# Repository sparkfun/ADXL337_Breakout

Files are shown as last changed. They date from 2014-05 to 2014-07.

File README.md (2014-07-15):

ADXL337 Breakout
================

[ADXL337 Breakout   
*Triple Axis Accelerometer Breakout-ADXL337 (SEN-12786)*](https://www.sparkfun.com/products/12786)

A Breakout Board for the ADXL337 Low Power 3-Axis ±3 g Accelerometer with Analog Output.

Repository Contents
-------------------
* **/Hardware** - All Eagle design files (.brd, .sch)
* **/Production** - Test bed files and production panel files
* **/Firmware** - All Arduino sketches for this product

License Information
-------------------
The hardware is released under [Creative Commons ShareAlike 4.0 International](https://creativecommons.org/licenses/by-sa/4.0/).

Distributed as-is; no warranty is given.

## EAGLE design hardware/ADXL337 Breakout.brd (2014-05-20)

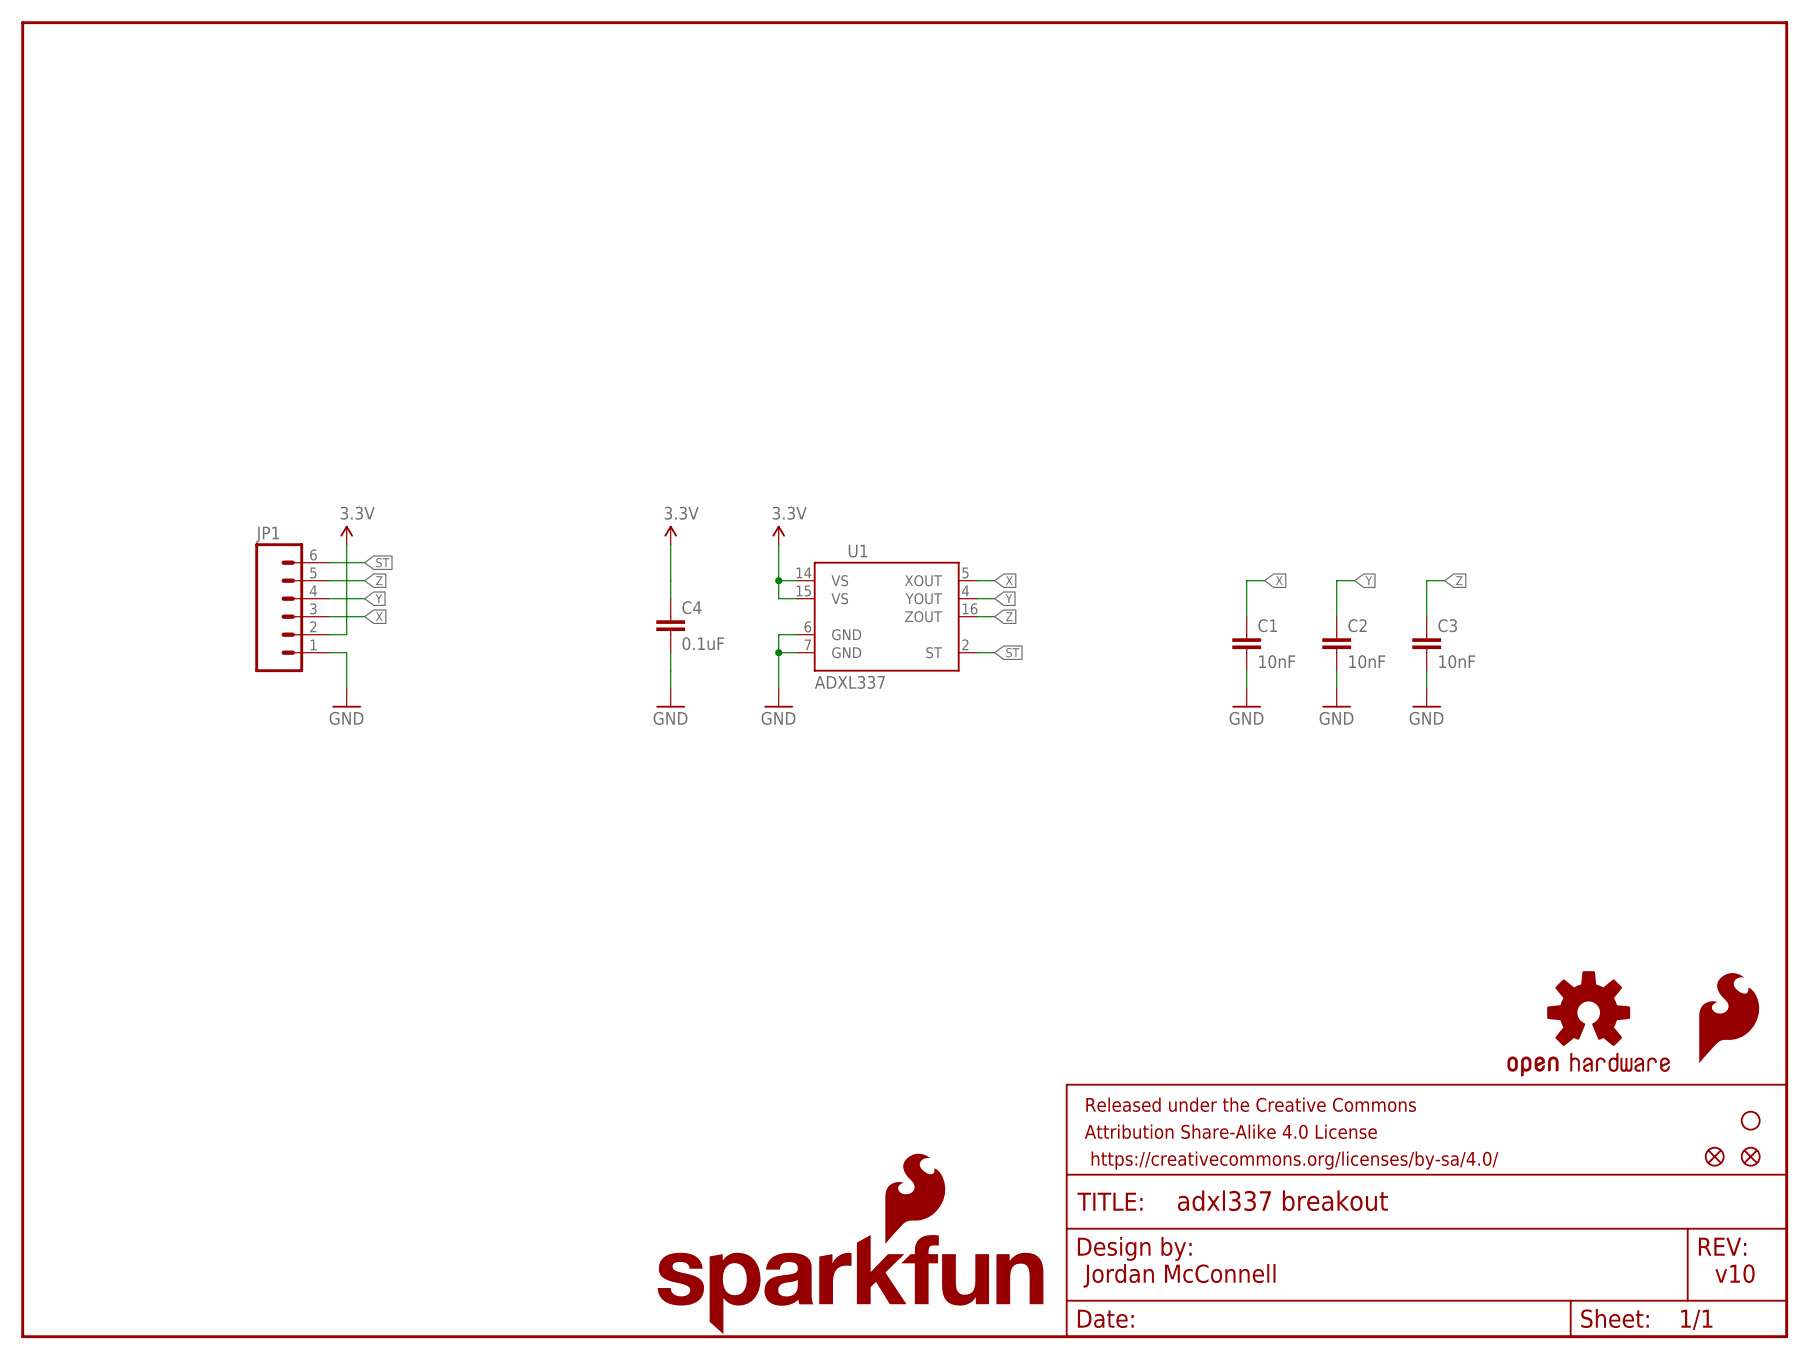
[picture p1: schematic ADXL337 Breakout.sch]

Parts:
C1, C2, C3: 10nF; 0603-CAP
C4: 0.1uF; 0603-CAP
FID1, FID2: FIDUCIAL1X2; FIDUCIAL-1X2
FRAME1: FRAME-LETTER; CREATIVE_COMMONS
JP1: M06SIP; 1X06
LOGO1: SFE_LOGO_FLAME.1_INCH; SFE_LOGO_FLAME_.1
LOGO2: OSHW-LOGOS; OSHW-LOGO-S
LOGO3: SFE_LOGO_NAME_FLAME.1_INCH; SFE_LOGO_NAME_FLAME_.1
STANDOFF1: STAND-OFF
U1: ADXL337; LFCSP_LQ-16

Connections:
3.3V: C4.1, JP1.2, U1.14 (VS), U1.15 (VS)
GND: C1.2, C2.2, C3.2, C4.2, JP1.1, U1.6 (GND), U1.7 (GND)
ST: JP1.6, U1.2 (ST)
X: C1.1, JP1.3, U1.5 (XOUT)
Y: C2.1, JP1.4, U1.4 (YOUT)
Z: C3.1, JP1.5, U1.16 (ZOUT)

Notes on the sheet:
Jordan McConnell
v10

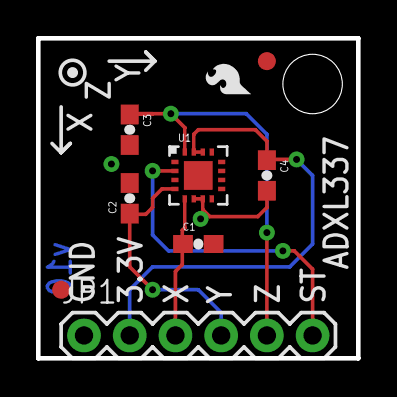
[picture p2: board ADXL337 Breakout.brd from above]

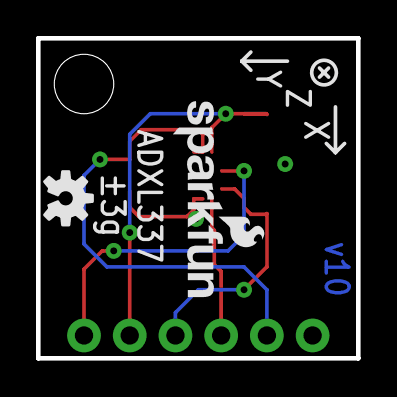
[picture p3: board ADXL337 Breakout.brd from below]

Board: 2 copper layers, 17.8 x 17.8 mm, 13 parts (2 on the bottom side), 6 nets.

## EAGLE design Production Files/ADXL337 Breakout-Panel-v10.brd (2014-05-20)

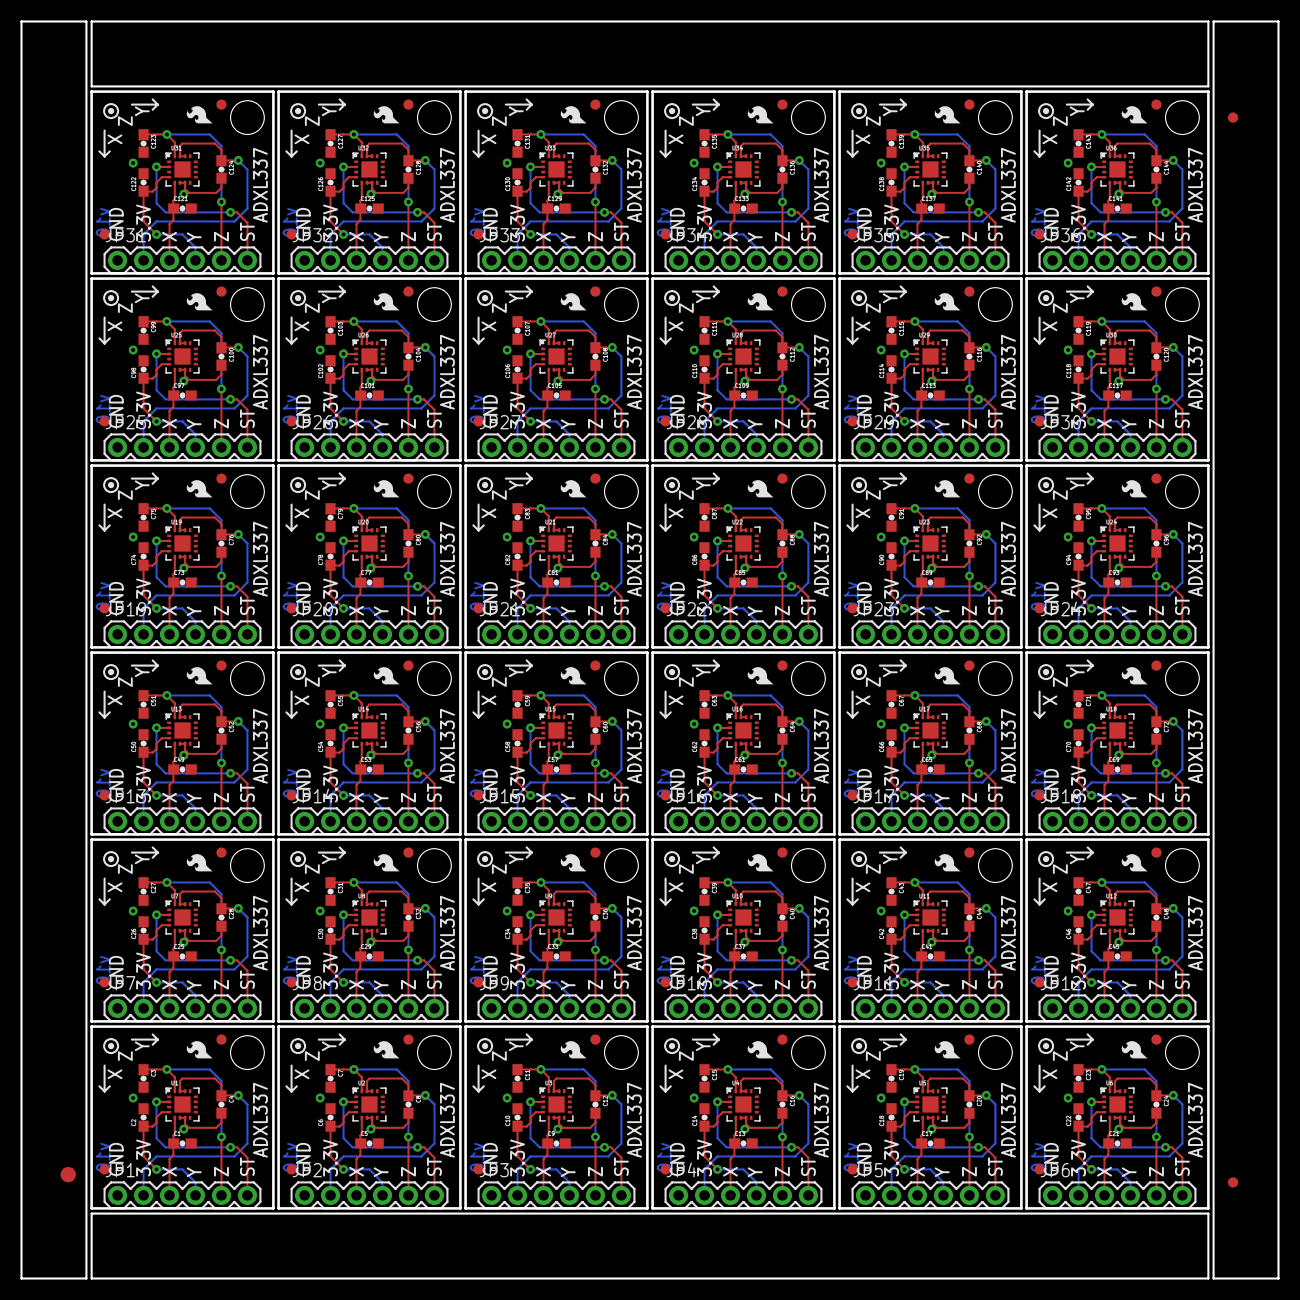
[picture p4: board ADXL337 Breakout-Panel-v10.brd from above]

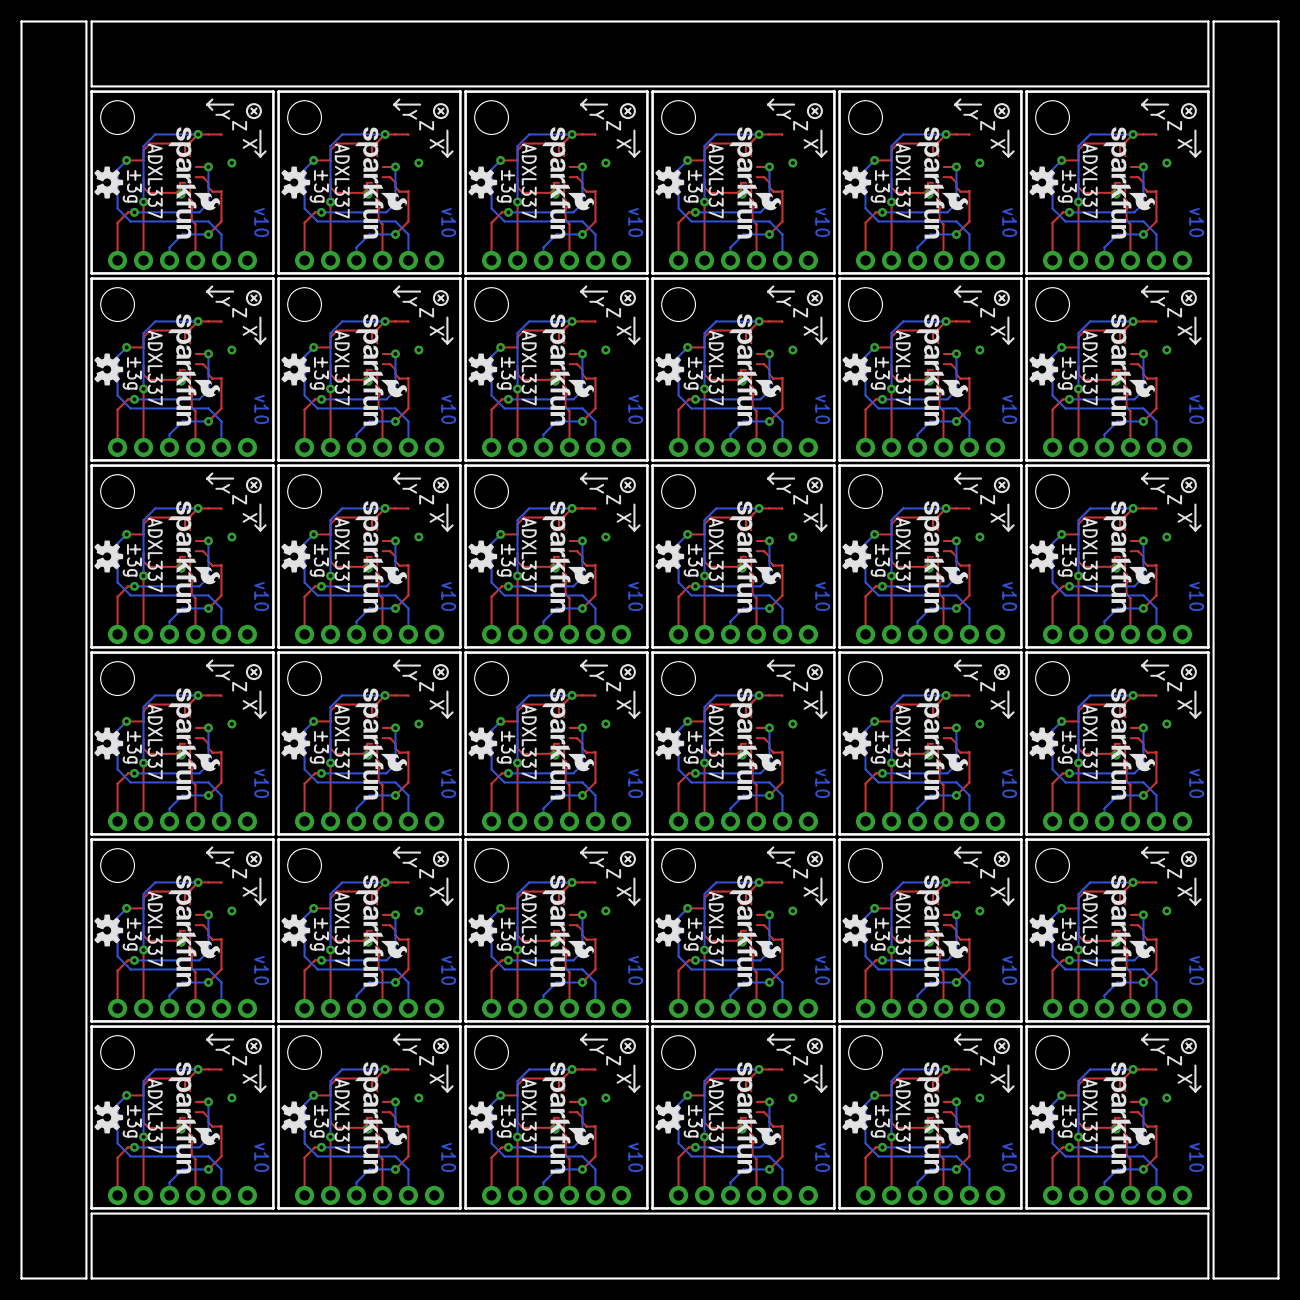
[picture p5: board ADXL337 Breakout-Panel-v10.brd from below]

Board: 2 copper layers, 122.9 x 122.9 mm, 435 parts (72 on the bottom side), 216 nets.

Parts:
C1, C2, C3, C5, C6, C7, C9, C10, C11, C13, C14, C15, C17, C18, C19, C21, C22, C23, C25, C26, C27, C29, C30, C31, C33, C34, C35, C37, C38, C39, C41, C42, C43, C45, C46, C47, C49, C50, C51, C53, C54, C55, C57, C58, C59, C61, C62, C63, C65, C66, C67, C69, C70, C71, C73, C74, C75, C77, C78, C79, C81, C82, C83, C85, C86, C87, C89, C90, C91, C93, C94, C95, C97, C98, C99, C101, C102, C103, C105, C106, C107, C109, C110, C111, C113, C114, C115, C117, C118, C119, C121, C122, C123, C125, C126, C127, C129, C130, C131, C133, C134, C135, C137, C138, C139, C141, C142, C143: 10nF; 0603-CAP
C4, C8, C12, C16, C20, C24, C28, C32, C36, C40, C44, C48, C52, C56, C60, C64, C68, C72, C76, C80, C84, C88, C92, C96, C100, C104, C108, C112, C116, C120, C124, C128, C132, C136, C140, C144: 0.1uF; 0603-CAP
E$1: FIDUCIAL-1.5X3
E$4, E$6: FIDUCIAL-1X2
FID1, FID2, FID3, FID4, FID5, FID6, FID7, FID8, FID9, FID10, FID11, FID12, FID13, FID14, FID15, FID16, FID17, FID18, FID19, FID20, FID21, FID22, FID23, FID24, FID25, FID26, FID27, FID28, FID29, FID30, FID31, FID32, FID33, FID34, FID35, FID36, FID37, FID38, FID39, FID40, FID41, FID42, FID43, FID44, FID45, FID46, FID47, FID48, FID49, FID50, FID51, FID52, FID53, FID54, FID55, FID56, FID57, FID58, FID59, FID60, FID61, FID62, FID63, FID64, FID65, FID66, FID67, FID68, FID69, FID70, FID71, FID72: FIDUCIAL1X2; FIDUCIAL-1X2
JP1, JP2, JP3, JP4, JP5, JP6, JP7, JP8, JP9, JP10, JP11, JP12, JP13, JP14, JP15, JP16, JP17, JP18, JP19, JP20, JP21, JP22, JP23, JP24, JP25, JP26, JP27, JP28, JP29, JP30, JP31, JP32, JP33, JP34, JP35, JP36: 1X06
LOGO1, LOGO4, LOGO7, LOGO10, LOGO13, LOGO16, LOGO19, LOGO22, LOGO25, LOGO28, LOGO31, LOGO34, LOGO37, LOGO40, LOGO43, LOGO46, LOGO49, LOGO52, LOGO55, LOGO58, LOGO61, LOGO64, LOGO67, LOGO70, LOGO73, LOGO76, LOGO79, LOGO82, LOGO85, LOGO88, LOGO91, LOGO94, LOGO97, LOGO100, LOGO103, LOGO106: SFE_LOGO_FLAME.1_INCH; SFE_LOGO_FLAME_.1
LOGO2, LOGO5, LOGO8, LOGO11, LOGO14, LOGO17, LOGO20, LOGO23, LOGO26, LOGO29, LOGO32, LOGO35, LOGO38, LOGO41, LOGO44, LOGO47, LOGO50, LOGO53, LOGO56, LOGO59, LOGO62, LOGO65, LOGO68, LOGO71, LOGO74, LOGO77, LOGO80, LOGO83, LOGO86, LOGO89, LOGO92, LOGO95, LOGO98, LOGO101, LOGO104, LOGO107: OSHW-LOGOS; OSHW-LOGO-S
LOGO3, LOGO6, LOGO9, LOGO12, LOGO15, LOGO18, LOGO21, LOGO24, LOGO27, LOGO30, LOGO33, LOGO36, LOGO39, LOGO42, LOGO45, LOGO48, LOGO51, LOGO54, LOGO57, LOGO60, LOGO63, LOGO66, LOGO69, LOGO72, LOGO75, LOGO78, LOGO81, LOGO84, LOGO87, LOGO90, LOGO93, LOGO96, LOGO99, LOGO102, LOGO105, LOGO108: SFE_LOGO_NAME_FLAME.1_INCH; SFE_LOGO_NAME_FLAME_.1
STANDOFF1, STANDOFF2, STANDOFF3, STANDOFF4, STANDOFF5, STANDOFF6, STANDOFF7, STANDOFF8, STANDOFF9, STANDOFF10, STANDOFF11, STANDOFF12, STANDOFF13, STANDOFF14, STANDOFF15, STANDOFF16, STANDOFF17, STANDOFF18, STANDOFF19, STANDOFF20, STANDOFF21, STANDOFF22, STANDOFF23, STANDOFF24, STANDOFF25, STANDOFF26, STANDOFF27, STANDOFF28, STANDOFF29, STANDOFF30, STANDOFF31, STANDOFF32, STANDOFF33, STANDOFF34, STANDOFF35, STANDOFF36: STAND-OFF
U1, U2, U3, U4, U5, U6, U7, U8, U9, U10, U11, U12, U13, U14, U15, U16, U17, U18, U19, U20, U21, U22, U23, U24, U25, U26, U27, U28, U29, U30, U31, U32, U33, U34, U35, U36: ADXL337; LFCSP_LQ-16

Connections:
3.3V: C4.1, JP1.2, U1.14, U1.15
3.3V1: C8.1, JP2.2, U2.14, U2.15
3.3V2: C12.1, JP3.2, U3.14, U3.15
3.3V3: C16.1, JP4.2, U4.14, U4.15
3.3V4: C20.1, JP5.2, U5.14, U5.15
3.3V5: C24.1, JP6.2, U6.14, U6.15
3.3V6: C28.1, JP7.2, U7.14, U7.15
3.3V7: C32.1, JP8.2, U8.14, U8.15
3.3V8: C36.1, JP9.2, U9.14, U9.15
3.3V9: C40.1, JP10.2, U10.14, U10.15
3.3V10: C44.1, JP11.2, U11.14, U11.15
3.3V11: C48.1, JP12.2, U12.14, U12.15
3.3V12: C52.1, JP13.2, U13.14, U13.15
3.3V13: C56.1, JP14.2, U14.14, U14.15
3.3V14: C60.1, JP15.2, U15.14, U15.15
3.3V15: C64.1, JP16.2, U16.14, U16.15
3.3V16: C68.1, JP17.2, U17.14, U17.15
3.3V17: C72.1, JP18.2, U18.14, U18.15
3.3V18: C76.1, JP19.2, U19.14, U19.15
3.3V19: C80.1, JP20.2, U20.14, U20.15
3.3V20: C84.1, JP21.2, U21.14, U21.15
3.3V21: C88.1, JP22.2, U22.14, U22.15
3.3V22: C92.1, JP23.2, U23.14, U23.15
3.3V23: C96.1, JP24.2, U24.14, U24.15
3.3V24: C100.1, JP25.2, U25.14, U25.15
3.3V25: C104.1, JP26.2, U26.14, U26.15
3.3V26: C108.1, JP27.2, U27.14, U27.15
3.3V27: C112.1, JP28.2, U28.14, U28.15
3.3V28: C116.1, JP29.2, U29.14, U29.15
3.3V29: C120.1, JP30.2, U30.14, U30.15
3.3V30: C124.1, JP31.2, U31.14, U31.15
3.3V31: C128.1, JP32.2, U32.14, U32.15
3.3V32: C132.1, JP33.2, U33.14, U33.15
3.3V33: C136.1, JP34.2, U34.14, U34.15
3.3V34: C140.1, JP35.2, U35.14, U35.15
3.3V35: C144.1, JP36.2, U36.14, U36.15
GND: C1.2, C2.2, C3.2, C4.2, JP1.1, U1.6, U1.7
GND1: C5.2, C6.2, C7.2, C8.2, JP2.1, U2.6, U2.7
GND2: C9.2, C10.2, C11.2, C12.2, JP3.1, U3.6, U3.7
GND3: C13.2, C14.2, C15.2, C16.2, JP4.1, U4.6, U4.7
GND4: C17.2, C18.2, C19.2, C20.2, JP5.1, U5.6, U5.7
GND5: C21.2, C22.2, C23.2, C24.2, JP6.1, U6.6, U6.7
GND6: C25.2, C26.2, C27.2, C28.2, JP7.1, U7.6, U7.7
GND7: C29.2, C30.2, C31.2, C32.2, JP8.1, U8.6, U8.7
GND8: C33.2, C34.2, C35.2, C36.2, JP9.1, U9.6, U9.7
GND9: C37.2, C38.2, C39.2, C40.2, JP10.1, U10.6, U10.7
GND10: C41.2, C42.2, C43.2, C44.2, JP11.1, U11.6, U11.7
GND11: C45.2, C46.2, C47.2, C48.2, JP12.1, U12.6, U12.7
GND12: C49.2, C50.2, C51.2, C52.2, JP13.1, U13.6, U13.7
GND13: C53.2, C54.2, C55.2, C56.2, JP14.1, U14.6, U14.7
GND14: C57.2, C58.2, C59.2, C60.2, JP15.1, U15.6, U15.7
GND15: C61.2, C62.2, C63.2, C64.2, JP16.1, U16.6, U16.7
GND16: C65.2, C66.2, C67.2, C68.2, JP17.1, U17.6, U17.7
GND17: C69.2, C70.2, C71.2, C72.2, JP18.1, U18.6, U18.7
GND18: C73.2, C74.2, C75.2, C76.2, JP19.1, U19.6, U19.7
GND19: C77.2, C78.2, C79.2, C80.2, JP20.1, U20.6, U20.7
GND20: C81.2, C82.2, C83.2, C84.2, JP21.1, U21.6, U21.7
GND21: C85.2, C86.2, C87.2, C88.2, JP22.1, U22.6, U22.7
GND22: C89.2, C90.2, C91.2, C92.2, JP23.1, U23.6, U23.7
GND23: C93.2, C94.2, C95.2, C96.2, JP24.1, U24.6, U24.7
GND24: C97.2, C98.2, C99.2, C100.2, JP25.1, U25.6, U25.7
GND25: C101.2, C102.2, C103.2, C104.2, JP26.1, U26.6, U26.7
GND26: C105.2, C106.2, C107.2, C108.2, JP27.1, U27.6, U27.7
GND27: C109.2, C110.2, C111.2, C112.2, JP28.1, U28.6, U28.7
GND28: C113.2, C114.2, C115.2, C116.2, JP29.1, U29.6, U29.7
GND29: C117.2, C118.2, C119.2, C120.2, JP30.1, U30.6, U30.7
GND30: C121.2, C122.2, C123.2, C124.2, JP31.1, U31.6, U31.7
GND31: C125.2, C126.2, C127.2, C128.2, JP32.1, U32.6, U32.7
GND32: C129.2, C130.2, C131.2, C132.2, JP33.1, U33.6, U33.7
GND33: C133.2, C134.2, C135.2, C136.2, JP34.1, U34.6, U34.7
GND34: C137.2, C138.2, C139.2, C140.2, JP35.1, U35.6, U35.7
GND35: C141.2, C142.2, C143.2, C144.2, JP36.1, U36.6, U36.7
ST: JP1.6, U1.2
ST1: JP2.6, U2.2
ST2: JP3.6, U3.2
ST3: JP4.6, U4.2
ST4: JP5.6, U5.2
ST5: JP6.6, U6.2
ST6: JP7.6, U7.2
ST7: JP8.6, U8.2
ST8: JP9.6, U9.2
ST9: JP10.6, U10.2
ST10: JP11.6, U11.2
ST11: JP12.6, U12.2
ST12: JP13.6, U13.2
ST13: JP14.6, U14.2
ST14: JP15.6, U15.2
ST15: JP16.6, U16.2
ST16: JP17.6, U17.2
ST17: JP18.6, U18.2
ST18: JP19.6, U19.2
ST19: JP20.6, U20.2
ST20: JP21.6, U21.2
ST21: JP22.6, U22.2
ST22: JP23.6, U23.2
ST23: JP24.6, U24.2
ST24: JP25.6, U25.2
ST25: JP26.6, U26.2
ST26: JP27.6, U27.2
ST27: JP28.6, U28.2
ST28: JP29.6, U29.2
ST29: JP30.6, U30.2
ST30: JP31.6, U31.2
ST31: JP32.6, U32.2
ST32: JP33.6, U33.2
ST33: JP34.6, U34.2
ST34: JP35.6, U35.2
ST35: JP36.6, U36.2
X: C1.1, JP1.3, U1.5
X1: C5.1, JP2.3, U2.5
X2: C9.1, JP3.3, U3.5
X3: C13.1, JP4.3, U4.5
X4: C17.1, JP5.3, U5.5
X5: C21.1, JP6.3, U6.5
X6: C25.1, JP7.3, U7.5
X7: C29.1, JP8.3, U8.5
X8: C33.1, JP9.3, U9.5
X9: C37.1, JP10.3, U10.5
X10: C41.1, JP11.3, U11.5
X11: C45.1, JP12.3, U12.5
X12: C49.1, JP13.3, U13.5
X13: C53.1, JP14.3, U14.5
X14: C57.1, JP15.3, U15.5
X15: C61.1, JP16.3, U16.5
X16: C65.1, JP17.3, U17.5
X17: C69.1, JP18.3, U18.5
X18: C73.1, JP19.3, U19.5
X19: C77.1, JP20.3, U20.5
X20: C81.1, JP21.3, U21.5
X21: C85.1, JP22.3, U22.5
X22: C89.1, JP23.3, U23.5
X23: C93.1, JP24.3, U24.5
X24: C97.1, JP25.3, U25.5
X25: C101.1, JP26.3, U26.5
X26: C105.1, JP27.3, U27.5
X27: C109.1, JP28.3, U28.5
X28: C113.1, JP29.3, U29.5
X29: C117.1, JP30.3, U30.5
X30: C121.1, JP31.3, U31.5
X31: C125.1, JP32.3, U32.5
X32: C129.1, JP33.3, U33.5
X33: C133.1, JP34.3, U34.5
X34: C137.1, JP35.3, U35.5
X35: C141.1, JP36.3, U36.5
Y: C2.1, JP1.4, U1.4
Y1: C6.1, JP2.4, U2.4
Y2: C10.1, JP3.4, U3.4
Y3: C14.1, JP4.4, U4.4
Y4: C18.1, JP5.4, U5.4
Y5: C22.1, JP6.4, U6.4
Y6: C26.1, JP7.4, U7.4
Y7: C30.1, JP8.4, U8.4
Y8: C34.1, JP9.4, U9.4
Y9: C38.1, JP10.4, U10.4
Y10: C42.1, JP11.4, U11.4
Y11: C46.1, JP12.4, U12.4
Y12: C50.1, JP13.4, U13.4
Y13: C54.1, JP14.4, U14.4
Y14: C58.1, JP15.4, U15.4
Y15: C62.1, JP16.4, U16.4
Y16: C66.1, JP17.4, U17.4
Y17: C70.1, JP18.4, U18.4
Y18: C74.1, JP19.4, U19.4
Y19: C78.1, JP20.4, U20.4
Y20: C82.1, JP21.4, U21.4
Y21: C86.1, JP22.4, U22.4
Y22: C90.1, JP23.4, U23.4
Y23: C94.1, JP24.4, U24.4
Y24: C98.1, JP25.4, U25.4
Y25: C102.1, JP26.4, U26.4
Y26: C106.1, JP27.4, U27.4
Y27: C110.1, JP28.4, U28.4
Y28: C114.1, JP29.4, U29.4
Y29: C118.1, JP30.4, U30.4
Y30: C122.1, JP31.4, U31.4
Y31: C126.1, JP32.4, U32.4
Y32: C130.1, JP33.4, U33.4
Y33: C134.1, JP34.4, U34.4
Y34: C138.1, JP35.4, U35.4
Y35: C142.1, JP36.4, U36.4
Z: C3.1, JP1.5, U1.16
Z1: C7.1, JP2.5, U2.16
Z2: C11.1, JP3.5, U3.16
Z3: C15.1, JP4.5, U4.16
Z4: C19.1, JP5.5, U5.16
Z5: C23.1, JP6.5, U6.16
Z6: C27.1, JP7.5, U7.16
Z7: C31.1, JP8.5, U8.16
Z8: C35.1, JP9.5, U9.16
Z9: C39.1, JP10.5, U10.16
Z10: C43.1, JP11.5, U11.16
Z11: C47.1, JP12.5, U12.16
Z12: C51.1, JP13.5, U13.16
Z13: C55.1, JP14.5, U14.16
Z14: C59.1, JP15.5, U15.16
Z15: C63.1, JP16.5, U16.16
Z16: C67.1, JP17.5, U17.16
Z17: C71.1, JP18.5, U18.16
Z18: C75.1, JP19.5, U19.16
Z19: C79.1, JP20.5, U20.16
Z20: C83.1, JP21.5, U21.16
Z21: C87.1, JP22.5, U22.16
Z22: C91.1, JP23.5, U23.16
Z23: C95.1, JP24.5, U24.16
Z24: C99.1, JP25.5, U25.16
Z25: C103.1, JP26.5, U26.16
Z26: C107.1, JP27.5, U27.16
Z27: C111.1, JP28.5, U28.16
Z28: C115.1, JP29.5, U29.16
Z29: C119.1, JP30.5, U30.16
Z30: C123.1, JP31.5, U31.16
Z31: C127.1, JP32.5, U32.16
Z32: C131.1, JP33.5, U33.16
Z33: C135.1, JP34.5, U34.16
Z34: C139.1, JP35.5, U35.16
Z35: C143.1, JP36.5, U36.16

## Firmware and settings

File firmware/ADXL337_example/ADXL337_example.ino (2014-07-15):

/******************************************************************************
ADXL337_example.ino
Simple example for using the ADXL337 accelerometer breakout.
Jordan McConnell @ SparkFun Electronics
3 July 2014
https://github.com/sparkfun/ADXL337_Breakout

This example collects raw accelerometer data from the ADXL337 sensor using
analog reads and then converts it into common units (g's) and prints the
result to the Serial Monitor.

Developed/Tested with:
Arduino Uno
Arduino IDE 1.0.5

This code is beerware.
Distributed as-is; no warranty is given. 
******************************************************************************/

// Make sure these two variables are correct for your setup
int scale = 3; // 3 (±3g) for ADXL337, 200 (±200g) for ADXL377
boolean micro_is_5V = true; // Set to true if using a 5V microcontroller such as the Arduino Uno, false if using a 3.3V microcontroller, this affects the interpretation of the sensor data

void setup()
{
  // Initialize serial communication at 115200 baud
  Serial.begin(115200);
}

// Read, scale, and print accelerometer data
void loop()
{
  // Get raw accelerometer data for each axis
  int rawX = analogRead(A0);
  int rawY = analogRead(A1);
  int rawZ = analogRead(A2);
  
  // Scale accelerometer ADC readings into common units
  // Scale map depends on if using a 5V or 3.3V microcontroller
  float scaledX, scaledY, scaledZ; // Scaled values for each axis
  if (micro_is_5V) // Microcontroller runs off 5V
  {
    scaledX = mapf(rawX, 0, 675, -scale, scale); // 3.3/5 * 1023 =~ 675
    scaledY = mapf(rawY, 0, 675, -scale, scale);
    scaledZ = mapf(rawZ, 0, 675, -scale, scale);
  }
  else // Microcontroller runs off 3.3V
  {
    scaledX = mapf(rawX, 0, 1023, -scale, scale);
    scaledY = mapf(rawY, 0, 1023, -scale, scale);
    scaledZ = mapf(rawZ, 0, 1023, -scale, scale);
  }
  
  // Print out raw X,Y,Z accelerometer readings
  Serial.print("X: "); Serial.println(rawX);
  Serial.print("Y: "); Serial.println(rawY);
  Serial.print("Z: "); Serial.println(rawZ);
  Serial.println();
  
  // Print out scaled X,Y,Z accelerometer readings
  Serial.print("X: "); Serial.print(scaledX); Serial.println(" g");
  Serial.print("Y: "); Serial.print(scaledY); Serial.println(" g");
  Serial.print("Z: "); Serial.print(scaledZ); Serial.println(" g");
  Serial.println();
  
  delay(2000); // Minimum delay of 2 milliseconds between sensor reads (500 Hz)
}

// Same functionality as Arduino's standard map function, except using floats
float mapf(float x, float in_min, float in_max, float out_min, float out_max)
{
  return (x - in_min) * (out_max - out_min) / (in_max - in_min) + out_min;
}

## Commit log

2014-02-28 v01 ready for review
    [ADXL337 Breakout.brd, ADXL337 Breakout.sch]
2014-03-07 fixed tcream layer on center pad of adxl337 ic
    [ADXL337 Breakout.brd, ADXL337 Breakout.sch]
2014-05-16 v10 ready for review
    [ADXL337 Breakout.brd, ADXL337 Breakout.sch]
2014-05-20 v10, ready for reds
    [ADXL337 Breakout.brd]
2014-05-20 created panel v10
    [ADXL337 Breakout-Panel-v10.brd]
2014-07-15 Added Arduino example sketch

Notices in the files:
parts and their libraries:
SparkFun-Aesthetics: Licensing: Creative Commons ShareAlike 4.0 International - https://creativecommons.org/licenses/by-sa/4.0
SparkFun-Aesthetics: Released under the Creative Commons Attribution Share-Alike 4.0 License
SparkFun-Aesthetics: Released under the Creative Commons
